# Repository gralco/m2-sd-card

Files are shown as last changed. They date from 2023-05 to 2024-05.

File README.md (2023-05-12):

# m2-sd-card

M.2 Key E MicroSD card board for the Librem 5. Using a NXP NVT4857UK, TI TXS0206, Diodes Inc. PI4ULS3V4857 SD 3.0-SDR104 compliant bidirectional level translator.

The contents of this repo is licensed under the GNU GPLv3+

### Manufacturing details

The board should be 0.8mm thick. Make sure you select the "Gold fingers" option when ordering.

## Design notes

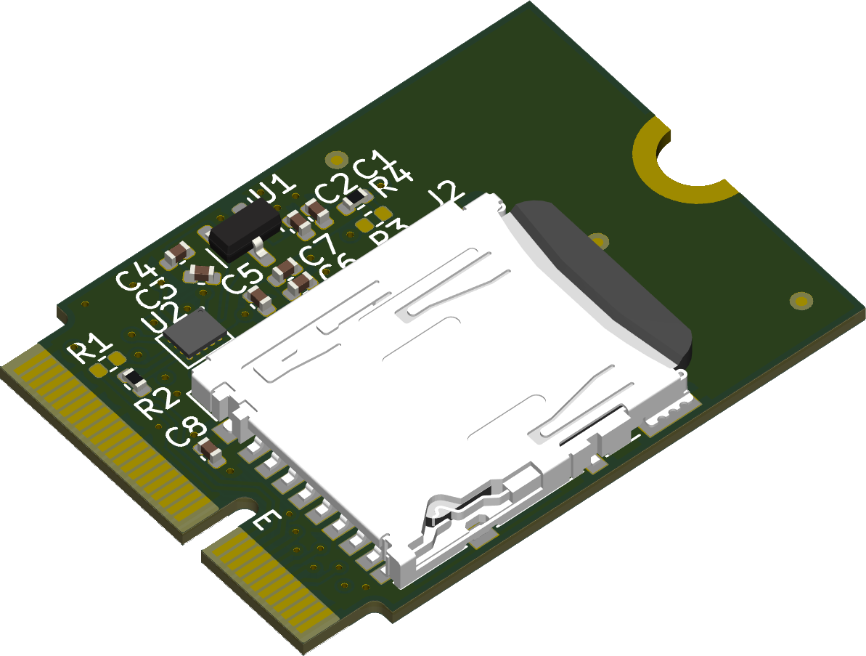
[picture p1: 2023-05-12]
m2-sd-card.png

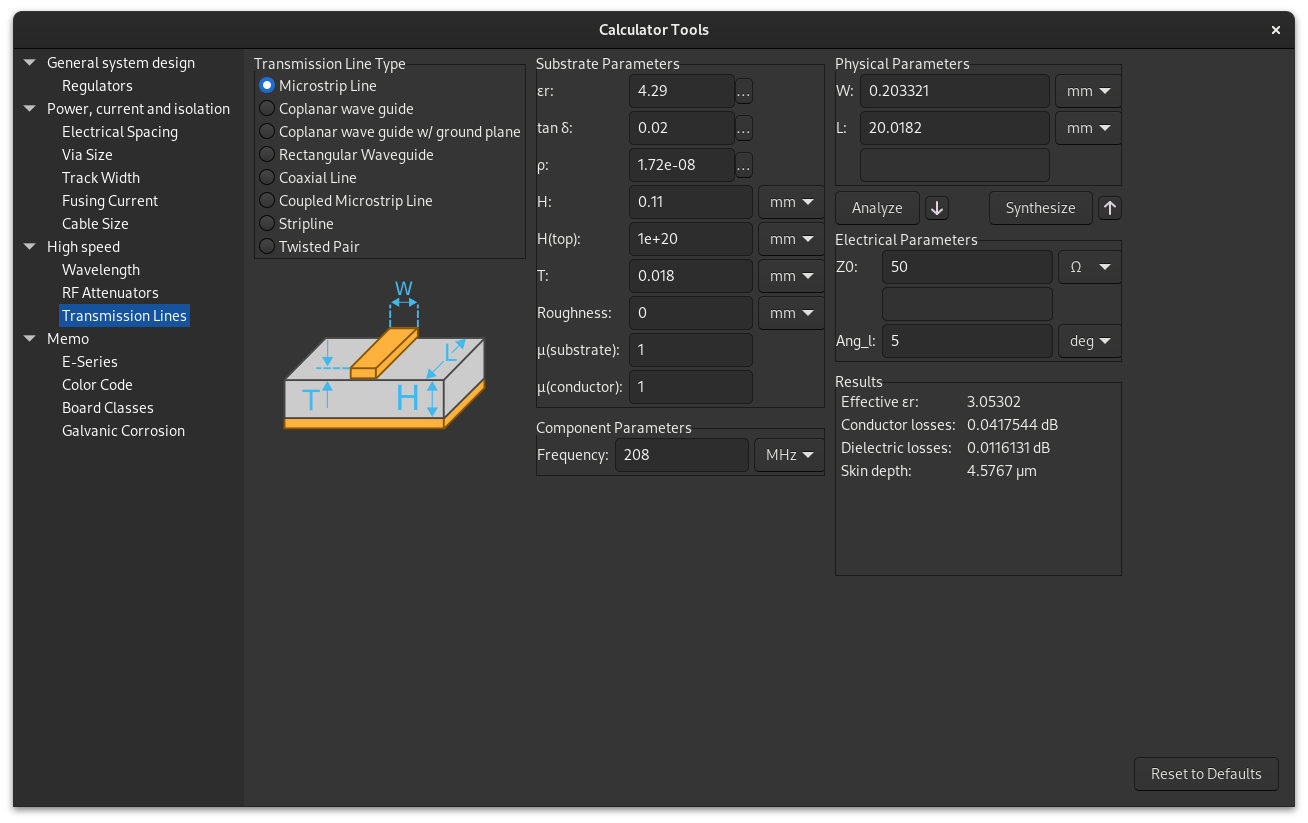
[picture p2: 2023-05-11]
calculations/50-Ohm-single-ended.png

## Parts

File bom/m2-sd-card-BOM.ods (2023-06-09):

Reference(s) | Qty | Value | Tolerance | DNP | MFG Name | MFG Part Num | Distrib PN | Distrib Link | Others | Datasheet
C1, C4 | 2 | 1uF | 10% |  | Samsung | CL05A105KO5NNNC | 187-CL05A105KO5NNNC | https://www.mouser.com/ProductDetail/Samsung-Electro-Mechanics/CL05A105KO5NNNC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 | https://www.mouser.com/c/passive-components/capacitors/mlccs/multilayer-ceramic-capacitors-mlcc-smd-smt/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 | https://media.digikey.com/pdf/Data%20Sheets/Samsung%20PDFs/CL05A105KO5NNNC_Spec_5-2-19.pdf
C2, C3, C8 | 3 | 100nF | 10% |  | Samsung | CL05A104KA5NNNC | 187-CL05A104KA5NNNC | https://www.mouser.com/ProductDetail/Samsung-Electro-Mechanics/CL05A104KA5NNNC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 | https://www.mouser.com/c/passive-components/capacitors/mlccs/multilayer-ceramic-capacitors-mlcc-smd-smt/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 | https://media.digikey.com/pdf/Data%20Sheets/Samsung%20PDFs/CL05A104KA5NNNC.pdf
C6, C7 | 2 | 22uF | 20% |  | KYOCERA AVX | CM05X5R226M06AH080 | 346-CM05X5R226M6AH80 | https://www.mouser.com/ProductDetail/KYOCERA-AVX/CM05X5R226M06AH080 | https://www.digikey.com/en/products/detail/kyocera-avx/CM05X5R226M06AH080/12397344 | https://www.mouser.com/datasheet/2/40/Kyocera_CM__STD__series2_052920-2585758.pdf
C5 | 1 | 2.2uF | 20% |  | Samsung | CL05A225MQ5NNNC | 187-CL05A225MQ5NNNC | https://www.mouser.com/ProductDetail/Samsung-Electro-Mechanics/CL05A225MQ5NNNC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 | https://www.mouser.com/c/passive-components/capacitors/mlccs/multilayer-ceramic-capacitors-mlcc-smd-smt/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 | https://media.digikey.com/pdf/Data%20Sheets/Samsung%20PDFs/CL05A225MQ5NNNC_Spec.pdf
J2 | 1 | Micro_SD_Card_Det2 | - |  | Hirose | DM3AT-SF-PEJM5 | 798-DM3AT-SF-PEJM5 | https://www.mouser.com/ProductDetail/Hirose-Connector/DM3AT-SF-PEJM5?qs=LZSZKJVF%252B2WTDKp%252BR7IYAQ%3D%3D | https://www.digikey.com/en/products/detail/hirose-electric-co-ltd/DM3AT-SF-PEJM5/2533565 | https://www.hirose.com/en/product/document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
R2 | 1 | 0 | - |  | Vishay | CRCW04020000Z0EDC | 71-CRCW04020000Z0EDC | https://www.mouser.com/ProductDetail/Vishay-Dale/CRCW04020000Z0EDC | https://www.mouser.com/c/passive-components/resistors/smd-resistors-chip-resistors/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 | https://www.vishay.com/docs/28773/crcwce3.pdf
R4 | 1 | 100k | 1% |  | Panasonic | ERJ-2RKF1003X | 667-ERJ-2RKF1003X | https://www.mouser.com/ProductDetail/Panasonic/ERJ-2RKF1003X | https://www.mouser.com/ProductDetail/Walsin/WR04X1003FTL?qs=1w%252B2sDiFrrHyM2yVwdrV0A%3D%3D | https://industrial.panasonic.com/cdbs/www-data/pdf/RDA0000/AOA0000C304.pdf
U1 | 1 | AP2120N-1.8 | - |  | Diodes Incorporated | AP2120N-1.8TRG1 | 621-AP2120N-1.8TRG1 | https://www.mouser.com/ProductDetail/Diodes-Incorporated/AP2120N-1.8TRG1?qs=x6A8l6qLYDC3T4tUK6BUJA%3D%3D | https://www.digikey.com/en/products/detail/diodes-incorporated/AP2120N-1-8TRG1/4470760 | https://www.diodes.com/assets/Datasheets/AP2120.pdf
U2 | 1 | NVT4857UK | - |  | NXP | NVT4857UKAZ | 771-NVT4857UKAZ | https://www.mouser.com/ProductDetail/NXP-Semiconductors/NVT4857UKAZ?qs=AQlKX63v8RukI4RsQ5PEGA%3D%3D | https://octopart.com/search?q=NVT4857UK&currency=USD&specs=0 | http://www.nxp.com/docs/en/data-sheet/NVT4857UK.pdf
Do Not Populate
R1, R3 | 2 | 0 | - | DNP | Vishay | CRCW04020000Z0EDC | 71-CRCW04020000Z0EDC | https://www.mouser.com/ProductDetail/Vishay-Dale/CRCW04020000Z0EDC | https://www.mouser.com/c/passive-components/resistors/smd-resistors-chip-resistors/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 | https://www.vishay.com/docs/28773/crcwce3.pdf

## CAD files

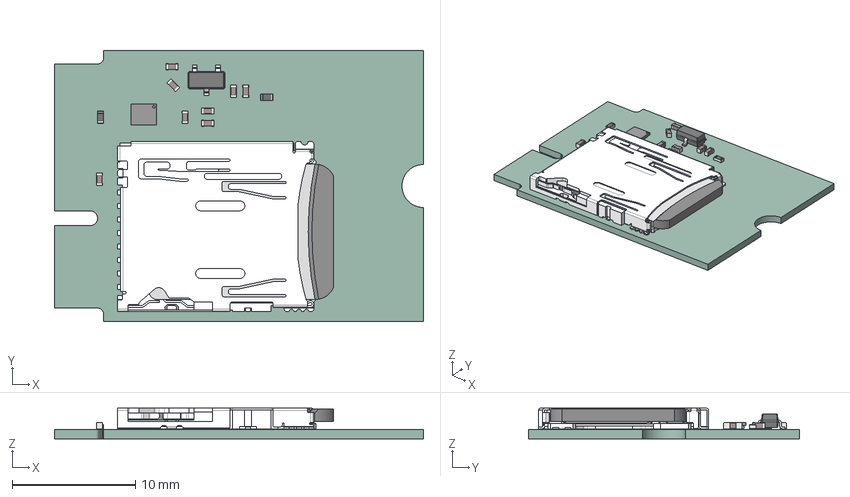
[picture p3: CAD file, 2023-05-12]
m2-sd-card.step
30.0 x 22.0 x 2.50 mm
_autosave-m2-sd-card PCB

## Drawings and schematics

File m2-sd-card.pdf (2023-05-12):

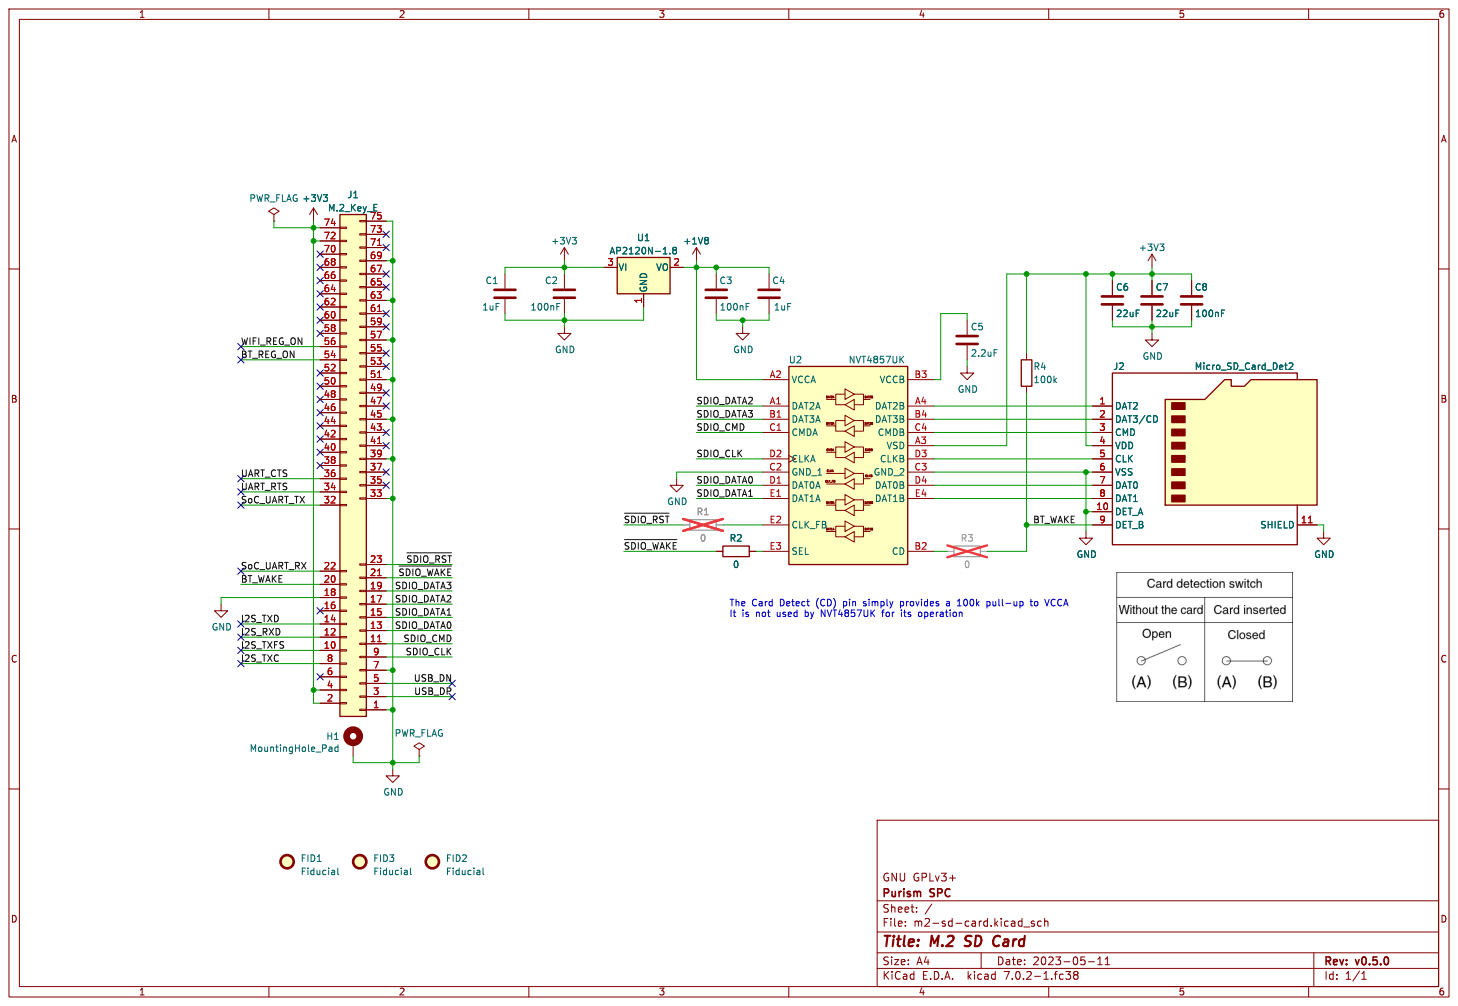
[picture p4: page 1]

1 VO 2 VI 3 U1 AP2120N-1.8 +1V8 H1 MountingHole_Pad FID1 Fiducial FID3 Fiducial

File: m2-sd-card.kicad_sch Sheet: / Purism SPC GNU GPLv3+

Id: 1/1 Title: M.2 SD Card

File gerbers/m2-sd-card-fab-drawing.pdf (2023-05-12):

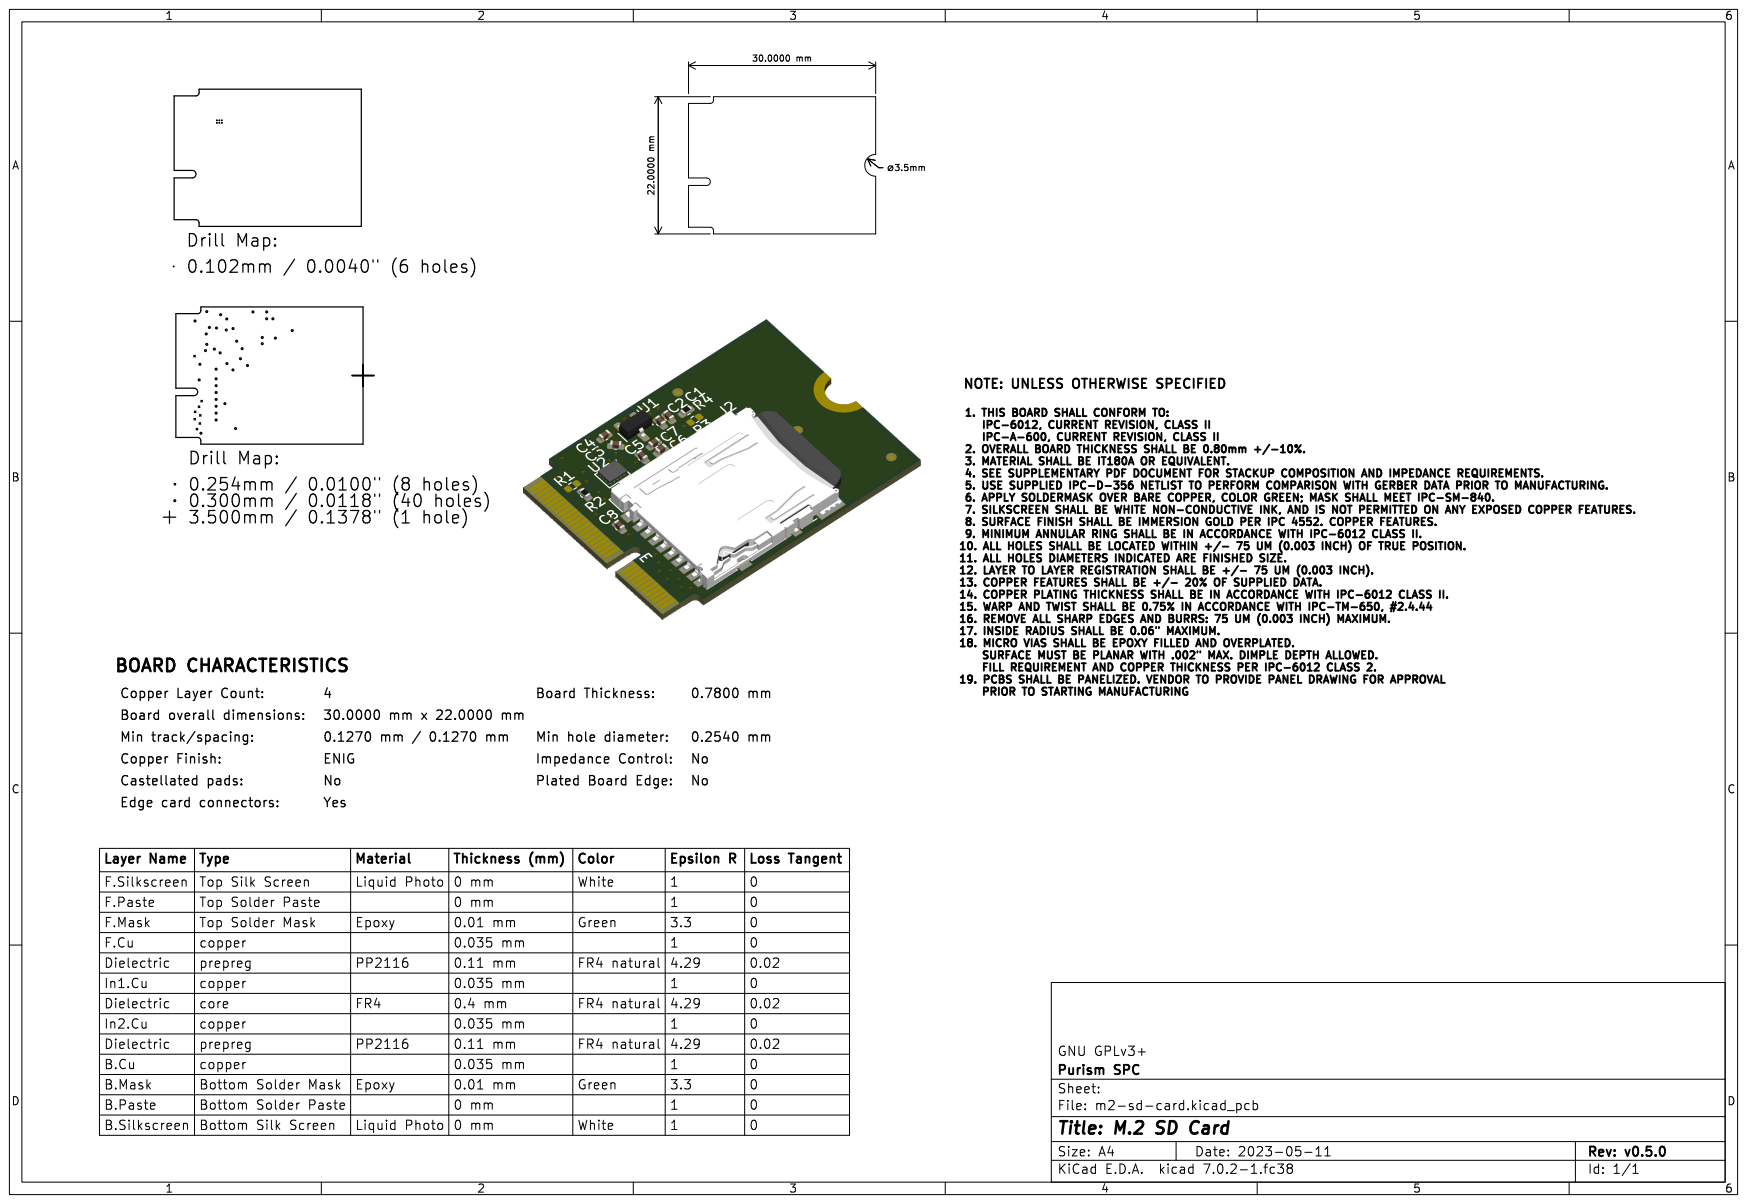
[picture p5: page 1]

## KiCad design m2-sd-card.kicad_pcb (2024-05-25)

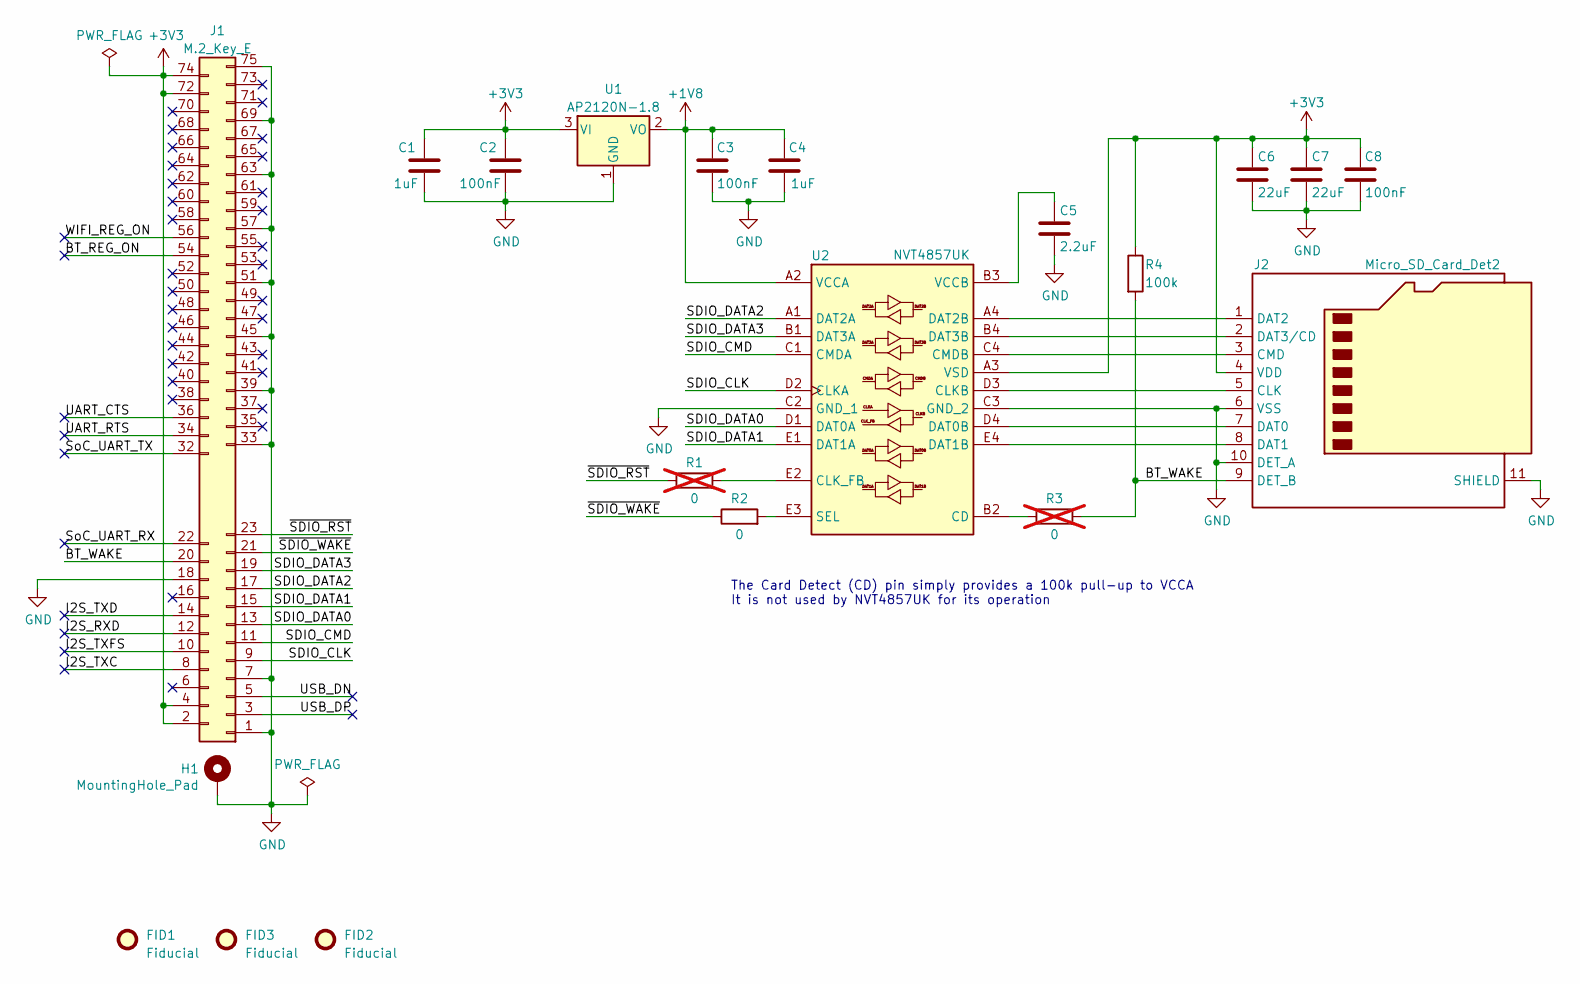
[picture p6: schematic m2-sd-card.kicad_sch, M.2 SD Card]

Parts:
C1, C4: 1uF; C_0402_1005Metric; Tolerance 10%; MFG Part Num CL05A105KO5NNNC
C2, C3, C8: 100nF; C_0402_1005Metric; Tolerance 10%; MFG Part Num CL05A104KA5NNNC
C5: 2.2uF; C_0402_1005Metric; Tolerance 20%; MFG Part Num CL05A225MQ5NNNC
C6, C7: 22uF; C_0402_1005Metric; Tolerance 20%; MFG Part Num CM05X5R226M06AH080
FID1, FID2, FID3: Fiducial; Fiducial_0.5mm_Mask1mm
H1: MountingHole_Pad; M.2_Mounting_Hole
J1: M.2_Key_E; M.2_Key_E_Gold_Fingers
J2: Micro_SD_Card_Det2; microSD_HC_Hirose_DM3AT-SF-PEJM5; MFG Part Num DM3AT-SF-PEJM5
R1, R3: 0; R_0402_1005Metric; MFG Part Num CRCW04020000Z0EDC; not fitted
R2: 0; R_0402_1005Metric; MFG Part Num CRCW04020000Z0EDC
R4: 100k; R_0402_1005Metric; Tolerance 1%; MFG Part Num ERJ-2RKF1003X
U1: AP2120N-1.8; SOT-23; MFG Part Num AP2120N-1.8TRG1
U2: NVT4857UK; MFG Part Num NVT4857UKAZ

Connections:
+1V8: C3.1, C4.1, U1.2 (VO), U2.A2 (VCCA)
+3V3: C1.1, C2.1, C6.1, C7.1, C8.1, J1.2, J1.4, J1.72, J1.74, J2.4 (VDD), R4.1, U1.3 (VI), U2.A3 (VSD)
/BT_REG_ON: J1.54
/BT_WAKE: J1.20, J2.9 (DET_B), R3.2, R4.2
/I2S_RXD: J1.12
/I2S_TXC: J1.8
/I2S_TXD: J1.14
/I2S_TXFS: J1.10
/SDIO_CLK: J1.9, U2.D2 (CLKA)
/SDIO_CMD: J1.11, U2.C1 (CMDA)
/SDIO_DATA0: J1.13, U2.D1 (DAT0A)
/SDIO_DATA1: J1.15, U2.E1 (DAT1A)
/SDIO_DATA2: J1.17, U2.A1 (DAT2A)
/SDIO_DATA3: J1.19, U2.B1 (DAT3A)
/SoC_UART_RX: J1.22
/SoC_UART_TX: J1.32
/UART_CTS: J1.36
/UART_RTS: J1.34
/USB_DN: J1.5
/USB_DP: J1.3
/WIFI_REG_ON: J1.56
/~SDIO_RST: J1.23, R1.1
/~SDIO_WAKE: J1.21, R2.1
GND: C1.2, C2.2, C3.2, C4.2, C5.2, C6.2, C7.2, C8.2, H1.1, J1.1, J1.7, J1.18, J1.33, J1.39, J1.45, J1.51, J1.57, J1.63, J1.69, J1.75, J2.6 (VSS), J2.10 (DET_A), J2.11 (SHIELD), U1.1 (GND), U2.C2 (GND_1), U2.C3 (GND_2)
unnamed: J2.5 (CLK), U2.D3 (CLKB)
unnamed: J2.3 (CMD), U2.C4 (CMDB)
unnamed: J2.7 (DAT0), U2.D4 (DAT0B)
unnamed: J2.8 (DAT1), U2.E4 (DAT1B)
unnamed: J2.1 (DAT2), U2.A4 (DAT2B)
unnamed: J2.2 (DAT3/CD), U2.B4 (DAT3B)
unnamed: R3.1, U2.B2 (CD)
unnamed: R1.2, U2.E2 (CLK_FB)
unnamed: R2.2, U2.E3 (SEL)
unnamed: C5.1, U2.B3 (VCCB)

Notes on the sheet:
The Card Detect (CD) pin simply provides a 100k pull-up to VCCA It is not used by NVT4857UK for its operation

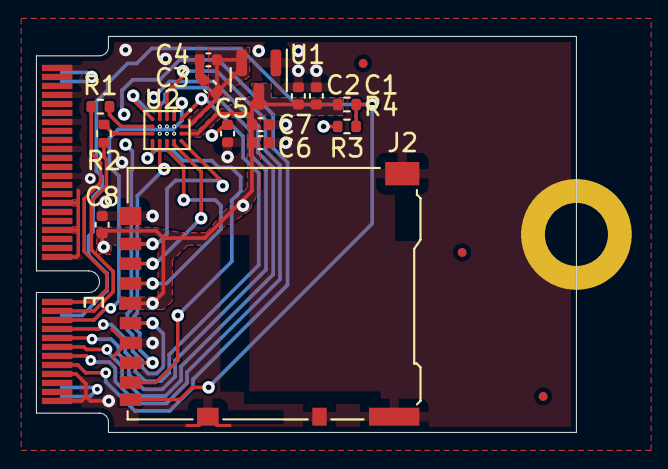
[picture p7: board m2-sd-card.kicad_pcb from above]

Board: 4 copper layers, 30.0 x 22.0 mm, 20 parts (0 on the bottom side), 22 nets.

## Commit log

2019-12-04 Add all of the project files
    [librem5-m2-breakout-B_Cu.gbr, librem5-m2-breakout-B_Mask.gbr, librem5-m2-breakout-B_Paste.gbr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]
2019-12-05 Add board name, version number, and copyright on the back silkscreen
    Removed the paste gerber files since they won't be used.
    [librem5-m2-breakout.kicad_pcb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]
2019-12-05 Reduce the soldermask clearance from 0.051mm to 0.01mm
    The soldermask dam is no longer being removed in the gerbers.
    [librem5-m2-breakout-B_Cu.gbr, librem5-m2-breakout-B_Mask.gbr, librem5-m2-breakout-B_SilkS.gbr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]
2019-12-05 Adjust the placement of the RXD and TXC silkscreen text
    [librem5-m2-breakout.kicad_pcb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]
2019-12-05 Make the USB net class's trace clearance 0.15mm
    The DRC violation that was occuring doesn't realize that the global clearance is less than the diff pair spacing.
    [librem5-m2-breakout.kicad_pcb]
2019-12-05 Adjust a couple of traces so they are routed slightly shorted
    [librem5-m2-breakout-B_Cu.gbr, librem5-m2-breakout-B_Mask.gbr, librem5-m2-breakout-B_SilkS.gbr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]
2019-12-16 Use the Connector:USB_OTG schematic symbol instead of the USB_B_Micro to get rid of the meaningless ERC error due to the "GND" pin being defined as a power output even though it should be defined as 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
    This commit doesn't change anything functionally, hence why the layout is untouched.
    [librem5-m2-breakout.sch]
2020-01-08 Add bill of materials
    [BOM.csv, librem5-m2-breakout.sch]
2020-02-02 Update the BOM to correctly reflect that the microUSB receptacle is the THT vertical Wurth Elektronik 614105150721
    [BOM.csv, librem5-m2-breakout.sch]
2023-05-08 Rename the project files to m2-sd-card and make the schematic pass ERC
    [BOM.csv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]
2023-05-09 Update the schematic to use the NVT4857UK SD 3.0-compliant bidirectional level translator
    Use Hirose DM3AT-SF-PEJM5 for the MicroSD card slot/connector (using
    KiCad's built-in library, with the footprint backed up in the project
    library).
    Add a AP2120N-1.8 1.8V LDO to supply NVT4857UK's VCCA.
    Create the NVT4857UK schematic symbol and footprint.
    Create the AP2120N-18 schematic symbol.
    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
    [m2-sd-card.kicad_sch]
2023-05-09 Fill out the remaining attributes for the passives and export the BOM and schematic as a PDF
    [BOM.csv, m2-sd-card-BOM.ods, m2-sd-card.kicad_sch]
2023-05-10 Import all of the footprints into the layout
    Delete the traces and footprints from the M.2 breakout board.
    Update the design rules constraints and physical stackup using PCBWay's
    manufacturing capabilities. These rules should work well for essentially
    any manufacturer that ends up being used.
    Adjust the NVT4857UK's WLCSP20 footprint according to NXP's recommended
    footprint and PCBWay's manufacturing capabilities (allowing for at least
    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
    [m2-sd-card.kicad_pcb]
2023-05-11 Hook up all of the nets and make sure DRC is passing
    Exceptions were made for the half-mounting hole and a silkscreen overlap
    with C3.
    Reset the reference designators to first free number starting at 0 so
    that they take up less space on the silkscreen.
    Layout is not completely done and still needs to be polished up.
    [m2-sd-card.kicad_pcb, m2-sd-card.kicad_sch]
2023-05-11 Add the calculation for the 50-Ohm single-ended trace width based on PCBWay's 0.8mm 4-layer stackup
2023-05-12 Finish the routing of the board and export the gerbers and all manufacturing files
    Add fab notes to the layout.
    Generate a fabrication drawing and include it in the gerbers directory
    since that is the location PCBWay will use (when this directory's
    contents are archived into a zip).
    Export the 3D step model of the board.
    Export the IPC-D-356 netlist file which will be used to verify the
    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
    [m2-sd-card-B_Cu.gbr, m2-sd-card-B_Mask.gbr, m2-sd-card-B_Silkscreen.gbr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]
2023-05-12 Create the board in Horizon EDA by importing the footprints from KiCad so that an ODB++ can be generated for the board
    The project in Horizon does not contain any of the nets, only the
    components since the copper is irrelevant for the PCB assembly.
    Verify that the ODB++ format works as expected using Siemens' ODB++
    viewer.
2023-05-12 Update the readme to describe the m2-sd-card board
2023-05-22 Add the EQ answers and IPC-D-365 files
    [W159429AS1D25 eq - answers.xls]
2023-05-22 Add the panelized gerbers provided by the manufacturer (PCBWay)
2023-05-23 Add the latest EQ question that was answered
    [Updated EQ W159429AS1D25 - answers.xls]
2023-05-25 Add an interactive BOM and move the existing BOM to the new bom directory
    [m2-sd-card-BOM.ods]
2023-06-09 Update the reference designators in the BOM to what the should be
    Previously, the designators started at *101 but were shorted to starting
    at *1 so that the text can fit on the silkscreen, but the BOM was not
    updated accordingly (until now).
    [m2-sd-card-BOM.ods]
2023-06-13 Mark R1 and R3 as "Exclude from bill of materials" in the layout
    [m2-sd-card.kicad_pcb]
2024-05-25 Add IPC-2581 file
    [m2-sd-card.kicad_pcb, m2-sd-card.kicad_sch]
